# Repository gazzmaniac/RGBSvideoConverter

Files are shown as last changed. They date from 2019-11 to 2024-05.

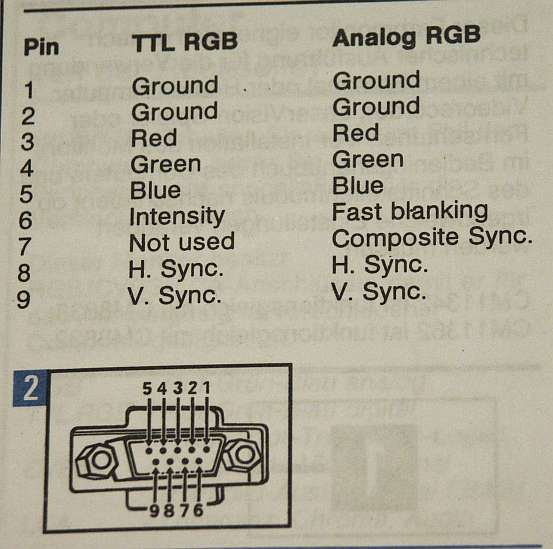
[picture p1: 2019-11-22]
RGB Input.jpg

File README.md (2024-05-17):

# RGBSvideoConverter
RGB to SVideo converter for Amiga computers

Comments May 2024
----------------------------------------------------
This project works fine, it's an easy way to get SVideo from your Amiga.
Be aware there are no buffers between the Amiga and video encoder.  This is a point of failure and I know of one video encoder that has failed because of it.  
In an ideal world I'd update it to have a video amplifier in between to protect both the Amiga and the encoder but with other open source alternatives (especially RGB2HDMI) now available there is very little point pursuing further development.  It may be of use for someone to incorporate into other projects.
If you do use this in a derivative project please give credit and make it open source.
Note the new license

Readme
----------------------------------------------------
Licensed under the CERN Open Hardware Licence Version 2 - Strongly Reciprocal (https://ohwr.org/)
Please be aware that some of the footprints may not be open source even though they are public domain.

This device is based around the AD723ARUZ PAL encoder.  It converts 15 kHz RGB signal to SVideo and Composite.  It is designed for and tested with the Amiga series of computers however it should work with other machines that output a 15 kHz RGB signal.  The circuit is substantially based on the examples given in the AD732ARUZ data sheet.

The video input is via a D9 socket with the same pinout as the Commodore 1084 monitor (except csync is not used) and power is 3.3-5v into a 5 mm DC power socket.  Power may be supplied from the Amiga.  A suitable cable would be:
AmigaD23 AdapterD9  AdapterPower   Signal
  16-20    1,2         sleeve       GND
    3       3                       Red
    4       4                       Green
    5       5                       Blue
    11      8                       HSync
    12      9                       VSync
    23                  pin         +5V

This project has been built and tested however no warranty is given.

Notes:
JP1 selects whether or not the YTrap filter is used.  There is no need to remove this.

Rev 1.1:
First open source release.
The only changes are in the silkscreens to reflect the now open nature of the project.

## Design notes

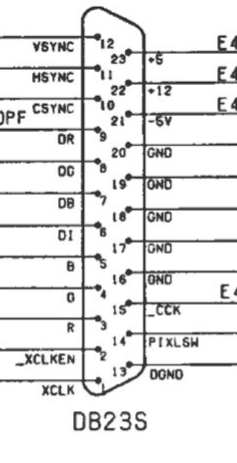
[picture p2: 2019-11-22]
D23 Output.png

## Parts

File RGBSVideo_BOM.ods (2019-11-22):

 | Red Keg Technologies RGB to Svideo adapter
 | Released under the TAPR Open Hardware License (www.tapr.org/OHL)
Id | Designator | Package | Quantity | Designation | Mouser ref
2 | J2 | CUI_PJ-102A | 1 | PJ-102A | 490-PJ-102A
4 | C1,C2,C11 | C_0805_2012Metric_Pad1.15x1.40mm_HandSolder | 3 | 10uF | 80-C0603C105M4V
5 | C3,C4,C5,C6,C8,C10 | C_0805_2012Metric_Pad1.15x1.40mm_HandSolder | 6 | 0.1u | 80-C0603C104M5R
7 | C7 | C_0805_2012Metric_Pad1.15x1.40mm_HandSolder | 1 | 33 pF | 603-C0603JRNPO9BN330
8 | C9 | C_0805_2012Metric_Pad1.15x1.40mm_HandSolder | 1 | 39 pF | 603-CC603JRNPO9BN390
21 | C12 | C_0805_2012Metric_Pad1.15x1.40mm_HandSolder | 1 | 18 pF | 963-TMK063CG180JT-F
10 | FB1 | BEADC1608X95N | 1 | BLM18AG102SZ1D | 81-BLM18AG102SZ1D
11 | IC1 | SOT65P210X110-6N | 1 | 74LVC2G04GW,125 | 771-74LVC2G04GW-G
12 | J1 | 1523409 | 1 | 152-3409 | 152-3409
13 | J3 | PJRAN1X1U03AUX | 1 | PJRAN1X1U03AUX | 502-PJRAN1X1U04AUX
14 | R1,R2,R3 | R_0805_2012Metric_Pad1.15x1.40mm_HandSolder | 3 | 75 | 71-CRCW060375R0FKEAC
15 | R4 | R_0805_2012Metric_Pad1.15x1.40mm_HandSolder | 1 | 1M | 603-RC0603FR-071ML
16 | R5 | R_0805_2012Metric_Pad1.15x1.40mm_HandSolder | 1 | 200 | 652-CR0603-FX2000ELF
17 | R6,R7,R8 | R_0805_2012Metric_Pad1.15x1.40mm_HandSolder | 3 | 300 | 603-RC0603FR-07300RL
18 | R9,R10,R11 | R_0805_2012Metric_Pad1.15x1.40mm_HandSolder | 3 | 374 | 603-RC0603FR-07374RL
19 | U1 | AD723ARUZ | 1 | AD723ARUZ | 584-AD723ARUZ
20 | Y1 | Crystal_SMD_HC49-SD_HandSoldering | 1 | 17.734 475 MHz 18 pF | 695-HC49US-177-U
22 | L1 | L_0805_2012Metric_Pad1.15x1.40mm_HandSolder | 1 | 68uH | 963-LB2012T680K
24 | J4 | CUI_MD-40FC | 1 | MD-40FC | 490-MD-40FC
 | Total for 10 | 219.16

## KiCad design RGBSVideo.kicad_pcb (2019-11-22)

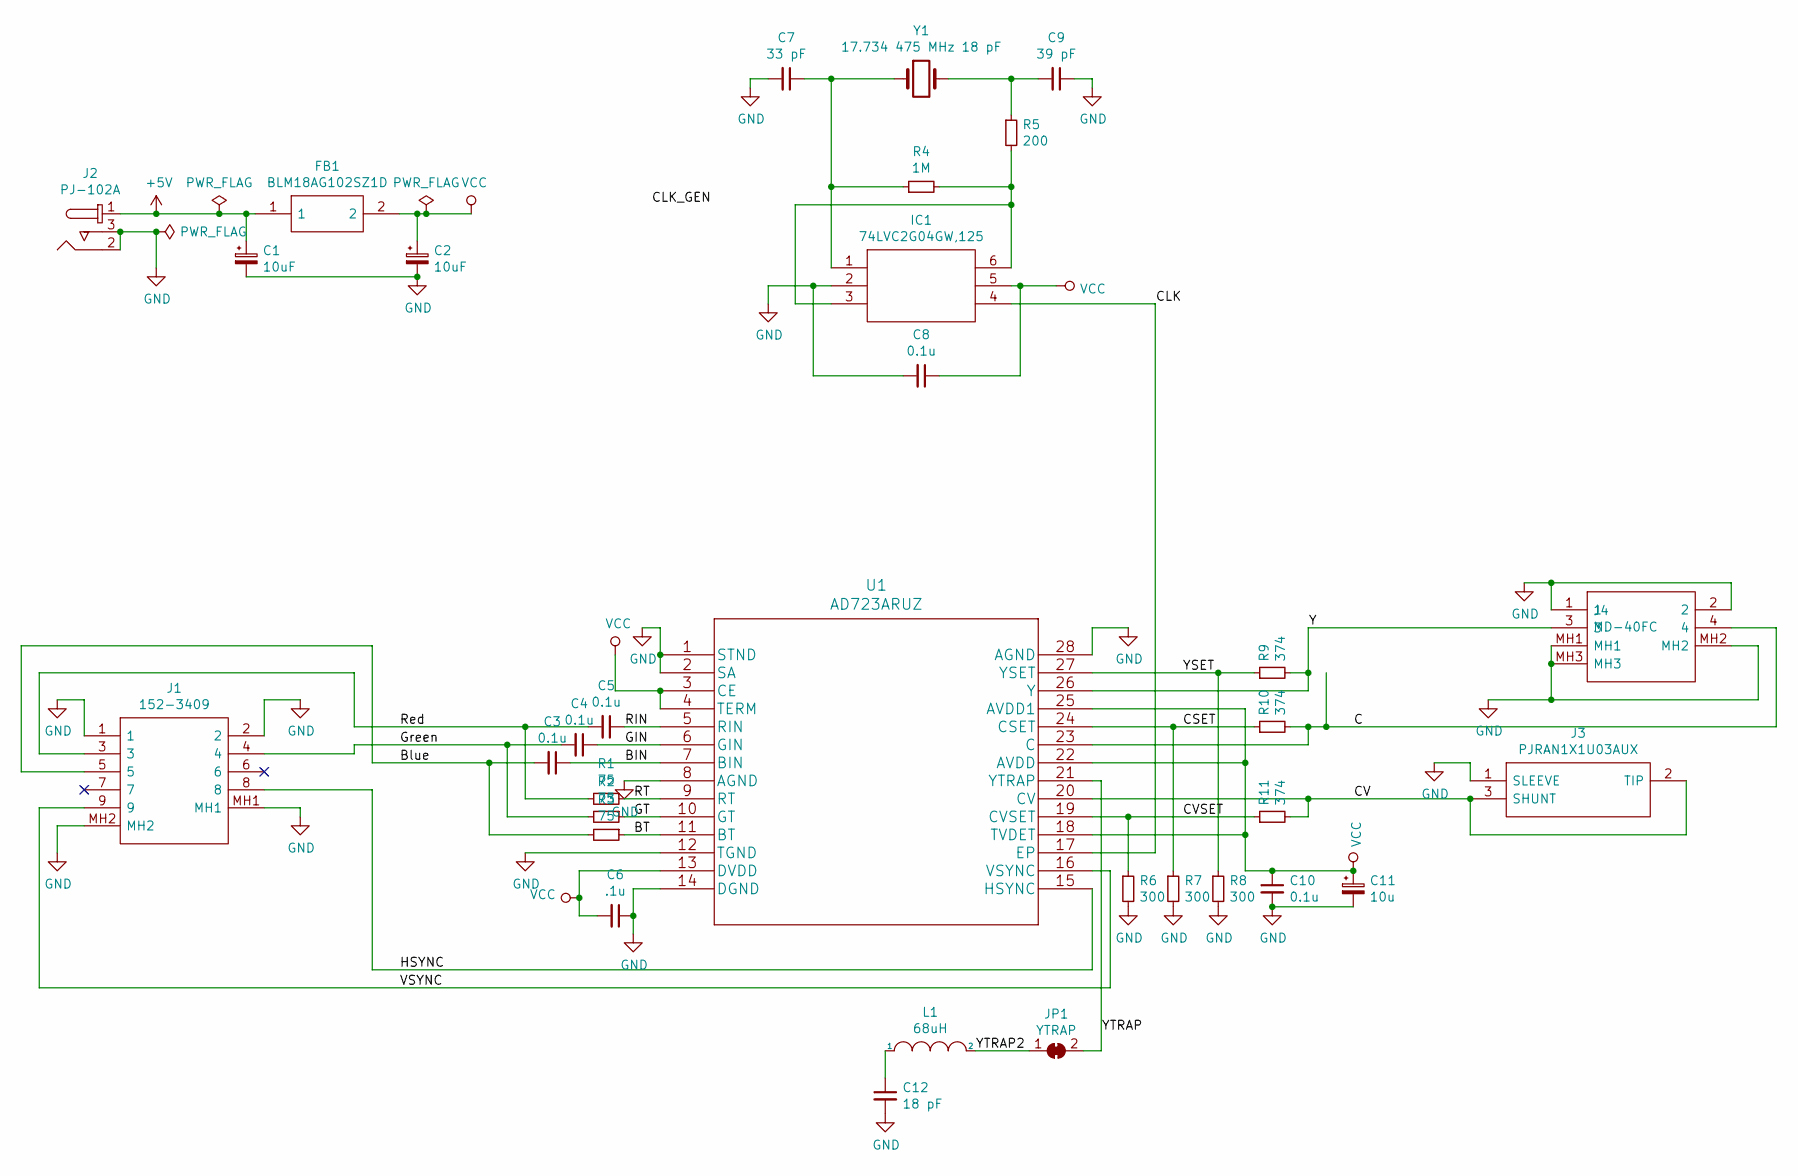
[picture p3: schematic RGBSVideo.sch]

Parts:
C1, C2: 10uF; C_0805_2012Metric_Pad1.15x1.40mm_HandSolder
C3, C4, C5, C8, C10: 0.1u; C_0805_2012Metric_Pad1.15x1.40mm_HandSolder
C6: .1u; C_0805_2012Metric_Pad1.15x1.40mm_HandSolder
C7: 33 pF; C_0805_2012Metric_Pad1.15x1.40mm_HandSolder
C9: 39 pF; C_0805_2012Metric_Pad1.15x1.40mm_HandSolder
C11: 10u; C_0805_2012Metric_Pad1.15x1.40mm_HandSolder
C12: 18 pF; C_0805_2012Metric_Pad1.15x1.40mm_HandSolder
FB1: BLM18AG102SZ1D; BEADC1608X95N; Mouser Part Number 81-BLM18AG102SZ1D
IC1: 74LVC2G04GW,125; SOT65P210X110-6N; Manufacturer_Part_Number 74LVC2G04GW,125; Mouser Part Number 771-74LVC2G04GW-G
J1: 152-3409; 1523409; Mouser Part Number 152-3409
J2: PJ-102A; CUI_PJ-102A; MPN PJ-102A; Digi-Key_PN CP-102A-ND
J3: PJRAN1X1U03AUX; Mouser Part Number 502-PJRAN1X1U03AUX
J4: MD-40FC; CUI_MD-40FC
JP1: YTRAP; SolderJumper-2_P1.3mm_Bridged_RoundedPad1.0x1.5mm
L1: 68uH; L_0805_2012Metric_Pad1.15x1.40mm_HandSolder
R1, R2, R3: 75; R_0805_2012Metric_Pad1.15x1.40mm_HandSolder
R4: 1M; R_0805_2012Metric_Pad1.15x1.40mm_HandSolder
R5: 200; R_0805_2012Metric_Pad1.15x1.40mm_HandSolder
R6, R7, R8: 300; R_0805_2012Metric_Pad1.15x1.40mm_HandSolder
R9, R10, R11: 374; R_0805_2012Metric_Pad1.15x1.40mm_HandSolder
U1: AD723ARUZ
Y1: 17.734 475 MHz 18 pF; Crystal_SMD_HC49-SD_HandSoldering

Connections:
+5V: C1.1, FB1.1, J2.1
/BIN: C3.1, U1.7 (BIN)
/BT: R3.1, U1.11 (BT)
/Blue: C3.2, J1.5, R3.2
/C: J4.4, R10.2, U1.23 (C)
/CLK: IC1.4, U1.17 (EP)
/CSET: R7.1, R10.1, U1.24 (CSET)
/CV: J3.2 (TIP), J3.3 (SHUNT), R11.2, U1.20 (CV)
/CVSET: R6.1, R11.1, U1.19 (CVSET)
/GIN: C4.1, U1.6 (GIN)
/GT: R2.1, U1.10 (GT)
/Green: C4.2, J1.4, R2.2
/HSYNC: J1.8, U1.15 (HSYNC)
/RIN: C5.1, U1.5 (RIN)
/RT: R1.1, U1.9 (RT)
/Red: C5.2, J1.3, R1.2
/VSYNC: J1.9, U1.16 (VSYNC)
/Y: J4.3, R9.2, U1.26 (Y)
/YSET: R8.1, R9.1, U1.27 (YSET)
/YTRAP: JP1.2 (B), U1.21 (YTRAP)
/YTRAP2: JP1.1 (A), L1.2
GND: C1.2, C2.2, C6.1, C7.2, C8.2, C9.1, C10.2, C11.2, C12.2, IC1.2, J1.1, J1.2, J1.MH1, J1.MH2, J2.2, J2.3, J3.1 (SLEEVE), J4.1, J4.2, J4.MH1, J4.MH2, J4.MH3, R6.2, R7.2, R8.2, U1.1 (STND), U1.2 (SA), U1.8 (AGND), U1.12 (TGND), U1.14 (DGND), U1.28 (AGND)
unnamed 22: C7.1, IC1.1, R4.1, Y1.1; also elsewhere on the board
unnamed 23: C9.2, R5.1, Y1.2; also elsewhere on the board
unnamed: C12.1, L1.1
unnamed: IC1.3, IC1.6, R4.2, R5.2
VCC: C2.1, C6.2, C8.1, C10.1, C11.1, FB1.2, IC1.5, U1.3 (CE), U1.4 (TERM), U1.13 (DVDD), U1.18 (TVDET), U1.22 (AVDD), U1.25 (AVDD1)

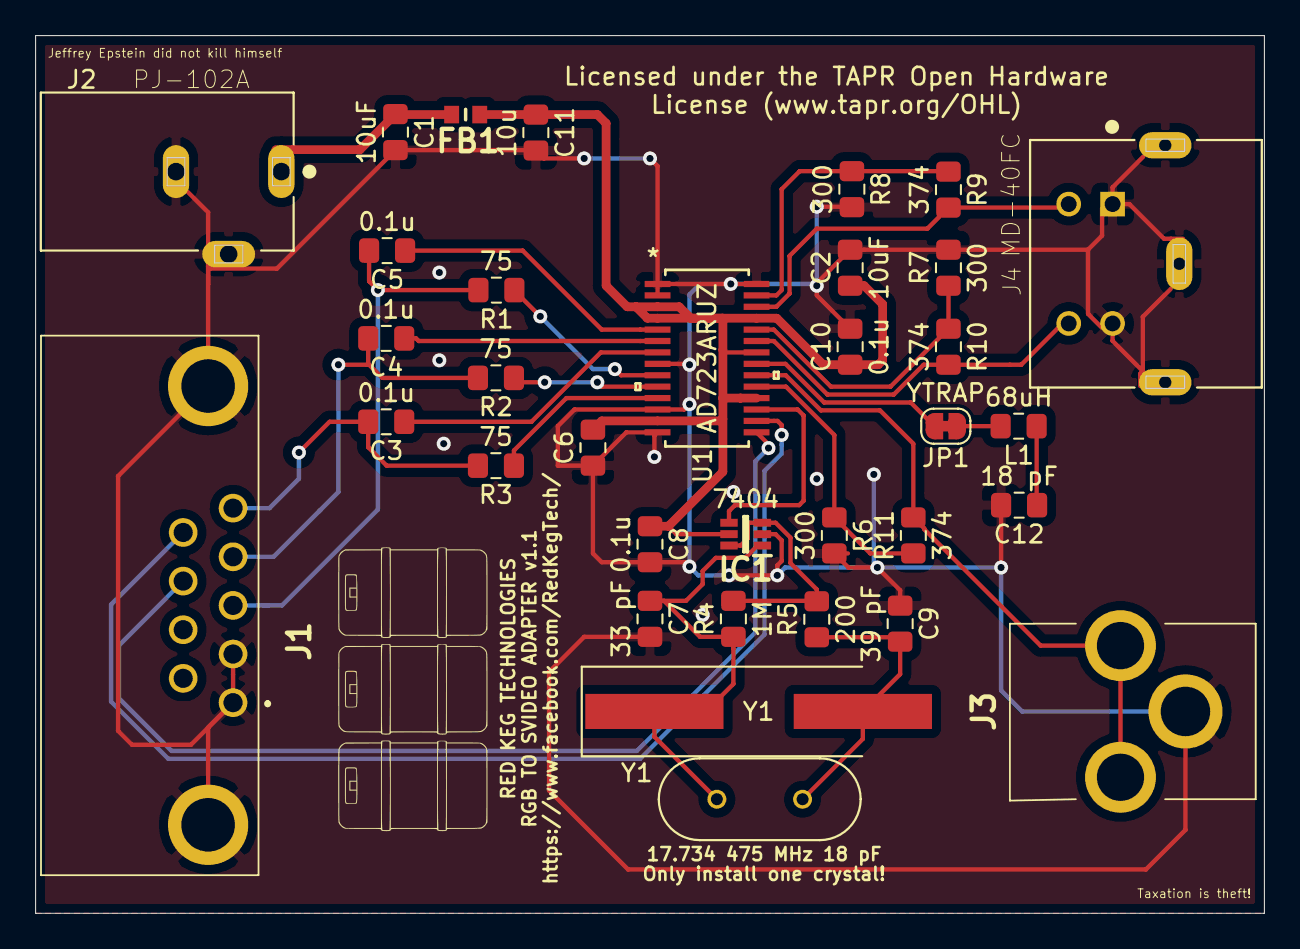
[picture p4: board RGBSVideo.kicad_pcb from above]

Board: 2 copper layers, 70.0 x 50.0 mm, 34 parts (0 on the bottom side), 27 nets.

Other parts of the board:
XTAL_HC49P488W43L1150T466H350: VAL**; XTAL_HC49P488W43L1150T466H350

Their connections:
unnamed 22: XTAL_HC49P488W43L1150T466H350.1; also elsewhere on the board
unnamed 23: XTAL_HC49P488W43L1150T466H350.2; also elsewhere on the board

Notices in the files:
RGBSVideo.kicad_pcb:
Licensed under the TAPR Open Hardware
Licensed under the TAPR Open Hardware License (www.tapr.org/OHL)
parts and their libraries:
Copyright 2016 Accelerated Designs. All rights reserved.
